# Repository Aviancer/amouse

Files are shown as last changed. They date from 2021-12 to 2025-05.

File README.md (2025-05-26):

# amouse

```
  __ _   _ __  ___ _  _ ___ ___ 
 / _` | | '  \/ _ \ || (_-</ -_)
 \__,_| |_|_|_\___/\_,_/__/\___====____
```

Anachro Mouse, a usb to serial mouse adapter.

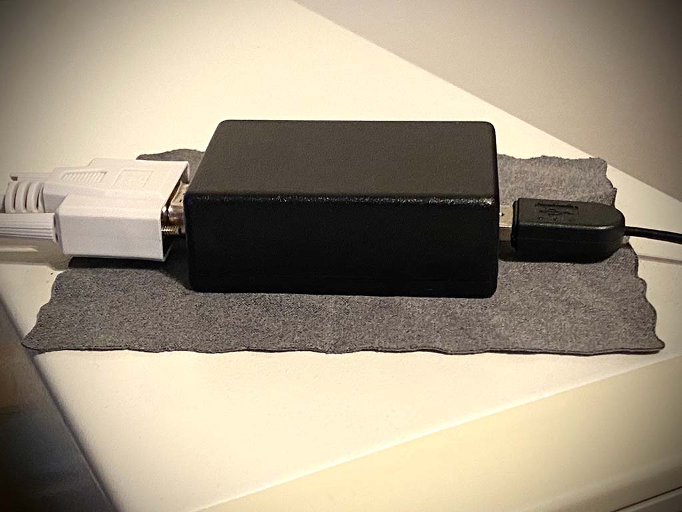
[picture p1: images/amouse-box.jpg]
Picture of a black box with USB and serial connector


This software will convert USB mouse inputs to a selectable serial mouse protocol for retro hardware. This way you can use a Raspberry Pico, a Raspberry Pi or an existing modern PC/laptop to mouse on your retro system.

If you do feel a bit more adventurous and would like to build a stand-alone adapter device, I have included the code to do this using a Raspberry Pico microcontroller. A circuit diagram is provided under the `diagrams` folder.

The adapter has been tested to work with DOS, Windows 3.1, Windows 95 and 98 serial mouse drivers so far.

# New and changed

Notable changes for users, see more detailed changelogs at the releases.

Since v1.6.0:
- Console is now accessed with `backspace` rather than `enter` key to avoid Windows ATDT autodetect
- Saving settings to non-volatile memory, both for Pico an Linux builds

Since v1.5.0:
- Fixed a regression in initializing mouse with Windows environments
- Changed from FIFO to queue based multi-threading model for much improved reliability in serial transmission

# Features

Input aggregation from USB data rates to serial, for making the mouse response smooth and accurate.

On-the-fly sensitivity control and easy menu based configuration over serial terminal.
Emulated protocols:
- Wheeled Microsoft IntelliPoint mouse (Both DOS and Windows Plug and Play compatible).
- Generic two button Microsoft serial Mouse, without wheel.
- Logitech three button mouse.

All protocols work on DOS and Windows with the appropriate mouse driver or ctmouse.exe available from the FreeDOS project.

Since version 1.6.0 you are able to save your settings to non-volatily flash memory or disk so that they get automatically loaded when the adapter starts.

# Controls

## On-the-fly sensitivity control

Once the mouse is initialized - hold down both left and right mouse buttons. Then additionally:
- Scroll mouse wheel up to add sensitivity
- Scroll mouse wheel down to reduce sensitivity

One mouse wheel click adds/reduces sensitivity by a factor of 0.2, you can adjust sensitivity between 0.2 and 3.0.

## Serial console for configuration

<video src="https://user-images.githubusercontent.com/80006672/147396198-eb4ab52f-2a5a-4799-a7e4-8fb58865289f.mp4" controls="controls" style="max-width: 720px;">
</video>

A serial console feature is provided for more advanced configuration of the features of the mouse adapter, allowing for more than what is practical with just mouse button shortcuts. The serial console uses the same COM port used for acting as a serial adapter and you can toggle between the modes easily. This way the computer can be used to configure the adapter and no additional hardware is required, on Linux you can of course also use direct cli arguments.

Things you can configure (as of 1.6.0):
- Sensitivity
- Serial mouse protocol
- Swap left and right buttons
- Store settings in non-volatile memory (flash)

Open a serial terminal program (kermit, etc) to the same COM port you connected the mouse to, use the following settings:
```
1200 baud
7 data bits
No parity
1 stop bit
No hardware flow control
```

Press `backspace` (in some terminals `ctrl+backspace`) to bring up the serial console, the adapter will switch to configuration mode and a menu will open. If you get scrambled characters, check all your terminal settings.
For an example you can enter: `3 11<enter>` to change the mouse sensitivity to 11 (1.1 in the above sensitivity scale).

Enter the `exit command` to the serial console after you are done configuring amouse, returning it to adapter mode. If you changed protocols, you may need to re-initialize the OS mouse driver.

### Saving your options

You can save your preferred settings so that they will be automatically loaded when you power on the adapter. These settings will be written to the same non-volatile flash memory that also stores the firmware. The currently selected settings are persisted to flash once you tell the adapter to save them, before that safe defaults will be loaded on boot. However once you have saved your settings, these settings will be automatically used the next time the adapter is powered on.

Navigate to `6) Read or write settings (Flash)` from the main menu. You can then:

1) Show help
2) Load settings from flash
3) Save settings to flash <--

If you make changes to your settings without saving, these will only remain in the memory until the adapter is power cycled. To update your settings you will need to save the settings to flash again. Using the on-the-fly sensitivity adjustment also changes the volatile in-memory settings.

With the Linux build the settings will be written to the users home directory at `~/.amouse.conf` (if you run the program as root with sudo, this means `/root/.amouse.conf`), in the same binary format as the Pico build uses.

# Linux version

Tested to work also on a Raspberry Pi.

The Linux version can be found under the 'linux' subdirectory. I wrote this initially as a prototype before moving on to writing a Raspberry Pico implementation of the same, but have continued to keep it up to date also.

The mouse is by default captured in exclusive mode so you can use it without worrying about sending inputs to the system running it. Non-exclusive mode is also supported.

## Requirements
- A working C building environment.
- libevdev (tested with 1.11.0-1, probably works with other versions)
- Superuser privileges (simple) or access to raw mouse and serial devices (requires changing perms, exercise left up to reader).
- A serial port on the computer running amouse. You can get away with a cheap USB to Serial adapter.
- A retro PC or alike for fun or productivity, I recommend using ctmouse.exe driver under DOS. amouse works fine for Windows 3.1, 95 and 98 drivers also.

## Preferred 
- The serial port (retropc)RTS -> CTC(amouse) pin is used by the mouse driver at the other end to signal initializing a mouse, amouse catches this for timing and responds appropriately. However this can also be manually timed if there are no other options.

## Build & install
```
cd linux
make
make install
```

make install will copy the binary to `/usr/local/bin` by default.

## Usage example

```
sudo amouse -m /dev/input/by-id/usb-<yourdevice>-event-mouse -s /dev/ttyUSB0 
```

Where ttyUSB0 in this case is for example a USB serial port adapter, naturally you can use an actual serial port as well if your computer features one.
Note that evdev requires access to a -event- generating device, just picking any `/dev/input` mouse device will not work.

You can try the following for finding the device file for your mouse:
`ls /dev/input/by-id/*event-mouse*`

If you are unable to find your mouse under there, you may have to look try out the various `/dev/input/event*` files instead.
The following may also provide some pointers for figuring out a `/dev/input/event*` number: `grep -H '' /sys/class/input/*/name`

If your serial cable/adapter isn't fully pinned (missing a CTS pin), you may use the `-i` (immediate ident) option bypass the automatic handling. In this case you will need to manually time it and launch the mouse driver and amouse at the same time. The timing can be pretty tight and require multiple attempts.

You can use the `-W` option to have the software write your current mouse options as the default settings when you run the software, the configuration will be written to `~/.amouse.conf` in the same binary format that is used to store the settings in flash for the stand-alone Pico adapter. As such it does not save any Linux specific settings like device paths.

`amouse -h` will also print help and list of flags available.

# Raspberry Pico (RP2040) version

Provides a stand-alone adapter running on a Raspberry Pico microcontroller for converting from USB to Serial Mouse.

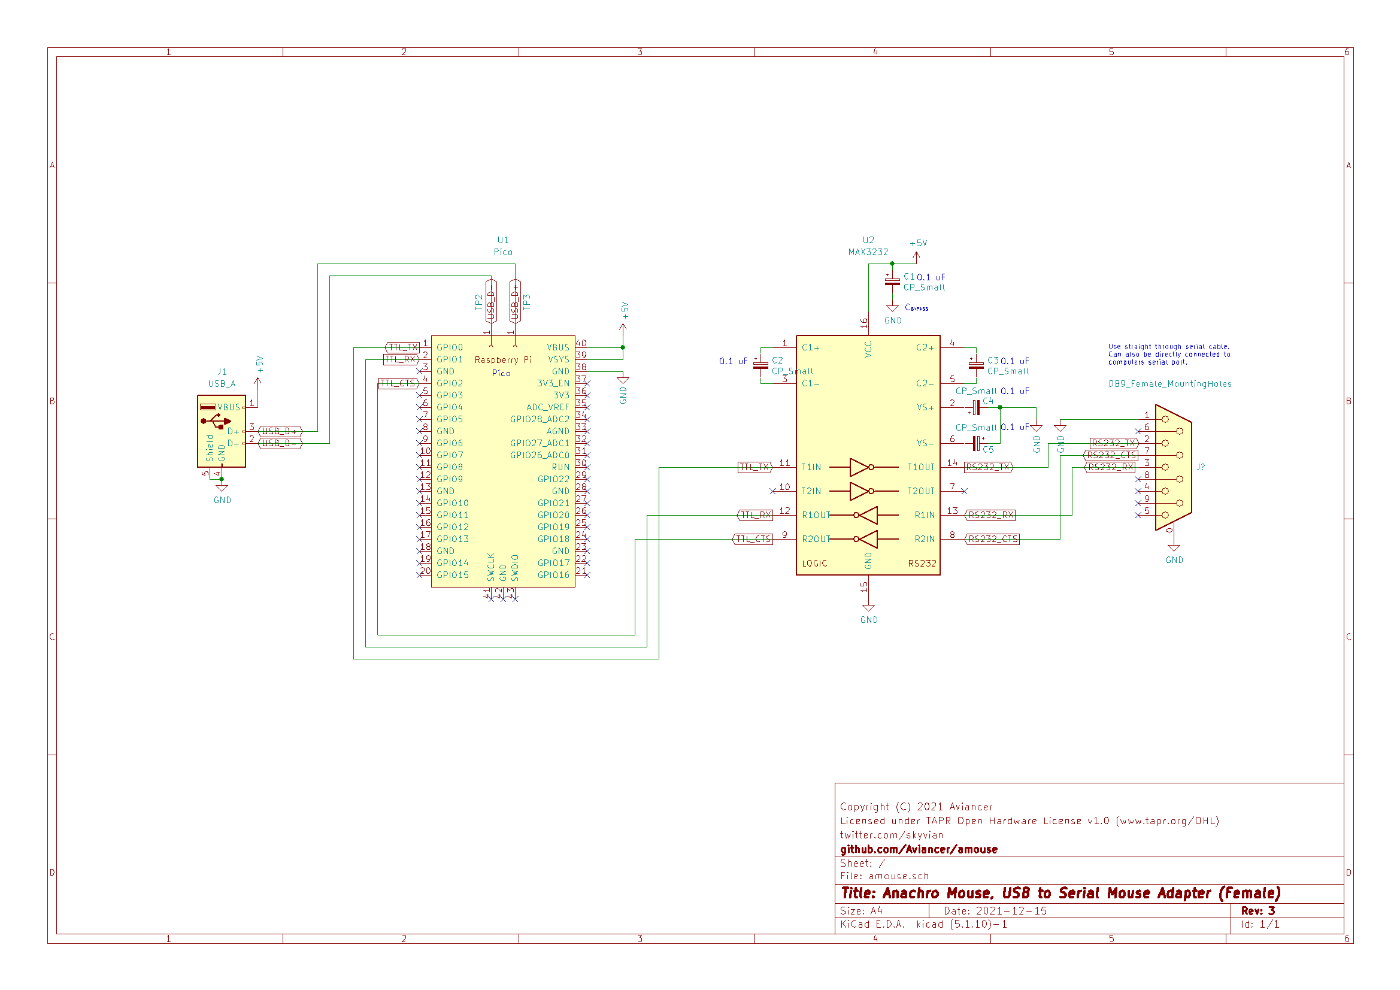
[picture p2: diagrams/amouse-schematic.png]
Electronic schematic of the adapter


## Requirements
- Basic soldering skills
- Working C building environment
- cmake version > 3.12
- Raspberry Pico SDK (Should auto-pull from git on cmake)

### Components
- A Raspberry Pico microcontroller
- One DIP MAX3232 chip or compatible, with 1x TX + 2x RX pins available.
- 5x 0.1uF capacitors (charge pumps for MAX3232, cbypass, etc)
- Serial header with RX, TX and CTS available
- USB-A header to solder on, or alternatively a USB micro to USB-A host adapter for connecting a USB mouse to the Pico USB port
- Few bits of wire/board to make connections
- A suitable serial cable for connecting from the adapter to the computers serial port (see diagram)
- A way to provide 5v power to the Pico (a USB charger or battery could be ideal)

## Build & install
```
cd pico/build
cmake ..
make
```

This will build `amouse.uf2` which can be flashed onto a Raspberry Pico.

To enter flashing mode with Raspberry Pico by holding down the small white button while connecting it to a USB port. Then simply copy `amouse.uf2` onto the Pico USB drive.

See `diagrams` directory for how to wire the Pico correctly to talk to a serial port.

## Usage example

- Connect your USB mouse to the adapter
- Connect the adapters serial port to the computers serial port
- Provide the Pico with 5v power (and appropriate grounding, etc)
- Run a mouse driver/start a serial mouse using OS on the computer

Provided that everything is connected up correctly, the adapter will auto-detect any mouse driver initialization from the PC and by default introduce itself as a Microsoft mouse. You can then use your USB mouse as a serial mouse.

# Planned future features

- [x] Storing settings like sensitivity and used mouse protocol in a non-volatile manner.
- [ ] Mouse Systems protocol.
- [ ] Graceful handling of reconnecting USB devices.
- [ ] DOS-native software for setting options without serial terminal program.

# FAQ

Q: Why Anachro Mouse?
A: A serial mouse is pretty anachronistic these days, but there's plenty of people who enjoy retro hardware and might find this rather useful. It also makes for a nice wordplay with 'a mouse' and 'anachromous'.

Q: Why a serial mouse?
A: Lots of people enjoy playing with retro PC hardware and I wanted there to be something that's easy with minimal hardware to use as a serial mouse while the latter are becoming increasingly rare or are breaking.

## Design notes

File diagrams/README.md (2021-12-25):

# Diagrams

All schematics were created in kicad.

## amouse-schematic.png

Main schematic with female serial port, can also be directly connected to a computers serial port. Use a straight serial cable for connecting.

## amouse-schematic_male.png 

Alternative schematic with male serial port, can also be directly connected to a computers serial port. Use a null modem cable with swapped RX/TX for connecting.

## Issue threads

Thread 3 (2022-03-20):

Does not work with Windows 3.11

mk2987, 2022-03-20:
First of all, thanks for creating this project!

I installed this on my Linux desktop and connected via serial port to my retro 486 machine. cutemouse.exe (tried v 2.1b and v 1.9) is able to detect the mouse. As a test, the mouse works fine in EDIT.COM. I run amouse with -d, and it keeps generating debug output about mouse telemetry as I move the pointer.
But Windows 3.11 isn't able to detect / use the mouse. I tried all the options available while setting up the mouse with c:\windows\setup.exe:
1) Choosing "Microsoft or IBM PS/2" makes the mouse pointer to not appear at all. The amouse binary on the Linux machine also stops generating any debug output. Maybe this is indicative of a problem?
2) Choosing Genius or Mouse Systems serial mouse makes the pointer appear, but it jumps about randomly. But I wouldn't expect this to work anyway.

I run the amouse binary this way (tried both with and without -w, no difference)
`sudo ./bin/amouse -w -d -m /dev/input/by-id/usb-MOSART_Semi._2.4G_Keyboard_Mouse-if01-event-mouse -s /dev/ttyS0`

Any ideas what could be going wrong?
Thanks!

Aviancer, 2022-03-20:
Thanks for contacting me, I'm happy to hear of interest in the project - it helps keep me motivated!

The current builds do have some problems being identified by Windows, since it seems like Windows is handling serial mouse identification in a bit special fashion that's been difficult to implement reliably. I've had a few builds that were being successfully recognized but had some latency issues in Windows, and I've been trying to rework my code so that both problems could be resolved for the next release.

I've actually not really done testing against Windows 3.1/3.11 but have concentrated primarily on DOS and 95/98. I'd be certainly interested in having proper support for Windows 3.X as well though, and testing that is helpful. My own kvm and physical hardware testing/capture setups don't cover 3.X currently.

I believe basic two button Microsoft mouse protocol might be working better at this time on the dev branch, but full on IntelliMouse PnP negotiation on 95 certainly is still failing. I'll check on this and get back to you. You can also find the dev branch here:
https://github.com/Aviancer/amouse/tree/dev

Aviancer, 2022-03-20:
I made a minor adjustment to the dev branch (commit 0d0d909) that allows the Linux build cli options (-w in this case) to select between MSWHEEL and MS2BUTTON protocols again - I'm also reworking this for more protocols. I tested that the 2 button basic Microsoft protocol is identing properly against Windows 95 and sent mouse movement and clicks.

The following command should hopefully now work for you with a standard Microsoft serial mouse driver on Windows (I am not able to test 3.X specifically right now):
`sudo ./bin/amouse -w -m /dev/input/by-id/usb-MOSART_Semi._2.4G_Keyboard_Mouse-if01-event-mouse -s /dev/ttyS0`

Let me know how it goes.

mk2987, 2022-03-21:
Thanks for the fix! I can confirm that as of commit `0d0d909` on the `dev` branch, the mouse works in Windows 3.11 when run as a two button MS mouse with the `-w` option of `amouse`. In Windows setup, I selected "Microsoft or IBM PS/2" as the mouse type. The command line used was:
`sudo ./bin/amouse -w -m /dev/input/by-id/usb-MOSART_Semi._2.4G_Keyboard_Mouse-if01-event-mouse -s /dev/ttyS0`

mk2987, 2022-03-21:
FWIW my mouse is connected to my Linux machine via a USB keyboard-mouse switch, it's great that the switch doesn't have any impact on amouse functionality. I did not notice any unacceptable latency either.

Aviancer, 2022-03-22:
Great, thanks for confirming that the change fixes the issue for Windows 3.X as well. This is a temporary fix and I need to rework selecting mouse protocols on the Linux build to allow more than two values to be selected (Logitech proto is now implemented also).

Happy to hear it's working nicely through the switch as well, I think it should work in most cases as long as there's nothing in between that would introduce the device as something else than as a mouse.

seritools, 2023-09-01:
Hey, I've built a Pi Pico amouse setup using an off-the-shelf MAX3232 to serial adapter (those that have RTS and CTS exposed) for use with my 486 machine, thank you for this project!

I'm also running into slight issues with Windows 3.11 - the mouse is fully detected and working under DOS (using the ctmouse driver), however under Windows, moving the mouse while any slightly CPU-intensive thing happens (starting Windows, starting a program, etc) it freezes the mouse. I can still see the status LED on the Pico lit up, and can see the TX led on the MAX3232 adapter blinking when moving the mouse.

A workaround seems to just reset the mouse while Windows is running, for some reason (e.g. start ctmouse in a dos window from within Windows again). Any idea what the issue could be?

Aviancer, 2025-04-28:
It's been a bit, but I've fixed a bunch of performance issues and some resulting regressions in mouse ident against Windows. The whole serial transmission logic has been reworked from FIFO based multi-threading to queue based multi-threading in the latest release. Hopefully this helps!!

Aviancer, 2025-05-14:
Alright! Tested both the stand-alone and the Linux build on Windows 3.1 with all the currently supported mouse protocols, everything looks good with building from commit 158756513d3dd1b3699b8a7b7d7ba0533516820f. Will probably be later released as 1.6.x, hoping to still implement the rest of configuration persistence.

Closed 2025-05-25.

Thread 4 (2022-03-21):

Makefile change needed to link on Raspbian 11

mk2987, 2022-03-21:
While amouse builds fine on my x86 Linux machine (Arch Linux), it was failing at link time on my Raspberry Pi:
`$ make
gcc -g -Wall -c src/include/serial.c -o src/include/serial.o
gcc -g -Wall -c src/../../shared/utils.c -o src/include/utils.o
gcc -g -Wall -c src/../../shared/mouse.c -o src/include/mouse.o
gcc -g -Wall -levdev -I/usr/include/libevdev-1.0/libevdev -I./include -o bin/amouse src/include/serial.c src/include/wrappers.c src/amouse.c ../shared/mouse.c ../shared/utils.c
/usr/bin/ld: /tmp/cclZh5iy.o: in function `open_usbinput':
/home/mkaushik/usb/amouse/linux/src/amouse.c:131: undefined reference to `libevdev_new_from_fd'
/usr/bin/ld: /home/mkaushik/usb/amouse/linux/src/amouse.c:136: undefined reference to `libevdev_has_event_type'
/usr/bin/ld: /home/mkaushik/usb/amouse/linux/src/amouse.c:137: undefined reference to `libevdev_has_event_code'
/usr/bin/ld: /home/mkaushik/usb/amouse/linux/src/amouse.c:138: undefined reference to `libevdev_has_event_code'
/usr/bin/ld: /home/mkaushik/usb/amouse/linux/src/amouse.c:139: undefined reference to `libevdev_has_event_code'
/usr/bin/ld: /home/mkaushik/usb/amouse/linux/src/amouse.c:140: undefined reference to `libevdev_has_event_code'
/usr/bin/ld: /home/mkaushik/usb/amouse/linux/src/amouse.c:141: undefined reference to `libevdev_has_event_code'
/usr/bin/ld: /home/mkaushik/usb/amouse/linux/src/amouse.c:142: undefined reference to `libevdev_free'
/usr/bin/ld: /tmp/cclZh5iy.o: in function `main':
/home/mkaushik/usb/amouse/linux/src/amouse.c:233: undefined reference to `libevdev_new_from_fd'
/usr/bin/ld: /home/mkaushik/usb/amouse/linux/src/amouse.c:324: undefined reference to `libevdev_next_event'
collect2: error: ld returned 1 exit status
make: *** [Makefile:30: amouse] Error 1
`
To fix this, we need to add the `--no-as-needed` flag to CFLAGS in the Makefile, or move `-levdev` to be after the object file names in the final build command. Apparently the linker on Raspbian 11 has `--as-needed` set by default (see the man page for ld for details on why this causes problems when -levdev is before the object files)

Aviancer, 2022-03-22:
I had a look over this and while I can't easily directly test this at the moment, I've changed the order of parameters for the final linking so that the libraries are included last after the objects. That appears to be the most compatible way to handle this issue as "--no-as-needed" is not a fully standard flag from what I'm seeing.

This change is in the current cba115f commit of the dev branch.

Aviancer, 2025-04-28:
No response in a few years so assuming fixed.

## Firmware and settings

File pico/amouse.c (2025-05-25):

/*
 *   __ _   _ __  ___ _  _ ___ ___ 
 *  / _` | | '  \/ _ \ || (_-</ -_)
 *  \__,_| |_|_|_\___/\_,_/__/\___=====_____)
 *
 * Anachro Mouse, a usb to serial mouse adaptor. Copyright (C) 2021-2025 Aviancer <oss+amouse@skyvian.me>
 *
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
 * You should have received a copy of the GNU Lesser General Public License along with this library; 
 * if not, write to the Free Software Foundation, Inc., 59 Temple Place, Suite 330, Boston, MA 02111-1307 USA
 *
*/

#include <time.h>
#include "stdbool.h"
#include "pico/flash.h"
#include "pico/stdlib.h"
#include "pico/multicore.h"
#include "pico/util/queue.h"
#include "hardware/irq.h"

#include "include/version.h"
#include "include/serial.h"
#include "include/storage.h"
#include "include/usb.h"
#include "../shared/console.h"
#include "../shared/utils.h"
#include "../shared/mouse.h"
#include "../shared/mouse_defs.h"
#include "../shared/settings.h"

#include "bsp/board.h"
#include "tusb.h"

// Technically could support multiple mice connected to the same system if we kept more mouse states in memory.


/*** Mouse state variables ****/

mouse_state_t mouse; // int values default to 0 

static uint32_t time_tx_target;  // Serial transmit timers target time
static uint32_t time_rx_target;  // Serial receive timers target time

uint8_t serial_buffer[2] = {0}; // Buffer for inputs from serial port.

// Aggregate movements before sending
CFG_TUSB_MEM_SECTION static hid_mouse_report_t usb_mouse_report_prev;

const uint LED_PIN = PICO_DEFAULT_LED_PIN;
bool led_state = false;

/*** Timing ***/

void queue_tx(mouse_state_t *mouse) {
  // Update timer target for next transmit
  // Use different send rate depending on protocol used (3 or 4 bytes)
  if(mouse->update > 3) { time_tx_target = time_us_32() + U_SERIALDELAY_4B; }
  else                  { time_tx_target = time_us_32() + U_SERIALDELAY_3B; }
}


/*** Mouse specific USB handling ***/

int test_mouse_button(uint8_t buttons_state, uint8_t button) {
  if(buttons_state & button) { return 1; }
  return 0;
}

static inline void process_mouse_report(mouse_state_t *mouse, hid_mouse_report_t const *p_report) {
 
  uint8_t button_changed_mask = p_report->buttons ^usb_mouse_report_prev.buttons; // xor to set bits true if any state is different.
  //if(button_changed_mask & p_report->buttons) { // Could be used to act only on any button down press.
  if(button_changed_mask) { // If button pressed or released
    mouse->force_update = 1;

    mouse->lmb = test_mouse_button(p_report->buttons, MOUSE_BUTTON_LEFT);
    mouse->rmb = test_mouse_button(p_report->buttons, MOUSE_BUTTON_RIGHT);
    push_update(mouse, mouse->mmb);

    if((button_changed_mask & MOUSE_BUTTON_MIDDLE)) {
      mouse->mmb = test_mouse_button(p_report->buttons, MOUSE_BUTTON_MIDDLE);
      if(g_mouse_protocol[g_mouse_options.protocol].buttons > 2) {
        push_update(mouse, true); 
      }
    }
  }
    
  // ### Handle relative movement ###
  // Clamp to larger than valid protocol output values to allow for sensitivity scaling.
  if(p_report->x) {
    mouse->x += p_report->x;
    mouse->x  = clampi(mouse->x, -36862, 36862); 
    push_update(mouse, mouse->mmb);
  }
  if(p_report->y) {
    mouse->y += p_report->y;
    mouse->y  = clampi(mouse->y, -36862, 36862);
    push_update(mouse, mouse->mmb);
  }
  if(p_report->wheel) {
    mouse->wheel += p_report->wheel;
    mouse->wheel  = clampi(mouse->wheel, -63, 63);
    if(g_mouse_protocol[g_mouse_options.protocol].wheel) {
      push_update(mouse, true); 
    }
  }

  // Update previous mouse state
  usb_mouse_report_prev = *p_report;
}

// External interface for delivering mouse reports to process_mouse_report()
// Allows keeping static context within amouse.c while tinyusb handling can be shifted to usb.c
extern void collect_mouse_report(hid_mouse_report_t const* p_report) {
  process_mouse_report(&mouse, p_report); // Passes full context with mouse and report without having to make them external/non-static.
}


/*** Core 1 thread to offload serial writes ***/

void core1_tightloop() {
  flash_safe_execute_core_init(); // Ensure core1 can be safetied for duration of writing to flash

  uint8_t serial_data;
  while(1) {
    //serial_queue_pop(&g_serial_queue, &serial_data); // TODO: Test if returns correct data now
    queue_remove_blocking(&g_serial_queue, &serial_data);
    uart_putc_raw(uart0, serial_data); // TODO: Make UART configurable.
  }
}

/*** Main init & loop ***/

int main() {

  // Initialize serial parameters 
  mouse_serial_init(0); // uart0

  // Initialize the global serial data queue
  queue_init(&g_serial_queue, sizeof(uint8_t), 80);

  // Should be launched before any interrupts
  multicore_launch_core1(core1_tightloop);

  // Set up initial state 
  //enable_pins(UART_RTS_BIT | UART_DTR_BIT);
  reset_mouse_state(&mouse);
  mouse.pc_state = CTS_UNINIT;

  // Set safe default options, support mouse wheel.
  g_mouse_options.protocol = PROTO_MSWHEEL;
  g_mouse_options.wheel = 1;
  g_mouse_options.sensitivity = 1.0;

  // Attempt to load saved settings from storage
  settings_decode(ptr_flash_settings(), &g_mouse_options);

  // Initialize USB
  tusb_init();

  // Onboard LED
  gpio_init(LED_PIN);
  gpio_set_dir(LED_PIN, GPIO_OUT);

  // Set initial serial timer targets
  time_tx_target = time_us_32() + U_SERIALDELAY_3B;
  time_rx_target = time_us_32() + U_FULL_SECOND; 

  bool cts_pin = false;

  while(1) {

    // Check for request for serial console
    // Repeating non-blocking reads is slow so instead we queue checks every now and then with timer.
    if(time_reached(time_rx_target)) {
      if(serial_read(0, serial_buffer, 1) > 0) {
        // Use backspace to enable console instead of \n\r to avoid ATDT autodetection on Windows
        if(serial_buffer[0] == '\b') {
    	    console(0);
        }
      }
      time_rx_target = time_us_32() + U_FULL_SECOND;
    }

    // Mouse handling

    cts_pin = gpio_get(UART_CTS_PIN);

    if(cts_pin) { // Computers RTS low, only pin we care about for MS drivers, etc.
      if(mouse.pc_state == CTS_UNINIT) { mouse.pc_state = CTS_LOW_INIT; }
      else if(mouse.pc_state == CTS_TOGGLED) { mouse.pc_state = CTS_LOW_RUN; }
    }

    // Mouse initiaizing request detected
    if(!cts_pin && (mouse.pc_state != CTS_UNINIT && mouse.pc_state != CTS_TOGGLED)) {
      gpio_put(LED_PIN, false); // DEBUG
      mouse.pc_state = CTS_TOGGLED;
      mouse_ident(0, g_mouse_options.wheel);
    }

    // Transmit only once we are initialized at least once. Unlike in DOS, Windows drivers will set CTS pin 
    // low after init which would inhibit transmitting. We will trust the driver to re-init if needed.
    if(mouse.pc_state > CTS_LOW_INIT) {
      if(!led_state) {
      	led_state = true;
      }

      tuh_task(); // tinyusb host task

      if(time_reached(time_tx_target) || mouse.force_update) {
        runtime_settings(&mouse);
      	input_sensitivity(&mouse);
	      update_mouse_state(&mouse);

      	queue_tx(&mouse); // Update next serial timing
	      if(mouse.update > 0) { serial_write(0, mouse.state, mouse.update); }
        reset_mouse_state(&mouse);
      }
    }

  }

  return(0);
}

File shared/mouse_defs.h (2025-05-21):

/*
 * Anachro Mouse, a usb to serial mouse adaptor. Copyright (C) 2025 Aviancer <oss+amouse@skyvian.me>
 *
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
 * You should have received a copy of the GNU Lesser General Public License along with this library; 
 * if not, write to the Free Software Foundation, Inc., 59 Temple Place, Suite 330, Boston, MA 02111-1307 USA
 *
*/

#ifndef MOUSE_DEFS_H_
#define MOUSE_DEFS_H_

/* Protocol definitions */
#define MOUSE_LMB_BIT 5 // Defines << shift for bit position
#define MOUSE_RMB_BIT 4
#define MOUSE_MMB_BIT 4 // Shift 4 times in 4th byte

typedef struct mouse_proto {
  char    name[12];
  uint8_t serial_ident[2]; // M, M3, MZ..
  int     serial_ident_len;
  int     buttons;
  bool    wheel;
  int     report_len;
} mouse_proto_t;

enum MOUSE_PROTOCOLS {
  PROTO_MS2BUTTON = 0, // 2 buttons, 3 bytes
  PROTO_LOGITECH  = 1, // 3 buttons, 3-4 bytes
  PROTO_MSWHEEL   = 2, // 3 buttons, wheel, 4 bytes.
  PROTO_MOUSESYS  = 3  // Mouse systems, TBD
};

// Delay between data packets for 1200 baud
#define U_FULL_SECOND 1000000L      // 1s in microseconds
#define U_SERIALDELAY_1B  7500      // 1 byte
#define U_SERIALDELAY_3B  22700     // 3 bytes (microseconds)
#define U_SERIALDELAY_4B  30000     // 4 bytes (microseconds)
// 1200 baud (bits/s) is 133.333333333... bytes/s
// 44.44.. updates per second with 3 bytes.
// 33.25.. updates per second with 4 bytes.
// ~0.0075 seconds per byte, target time calculated for 4 bytes.
#define NS_FULL_SECOND    1000000000L // 1s in nanoseconds
#define NS_SERIALDELAY_1B   7500000   // 1 byte
#define NS_SERIALDELAY_3B   22700000  // 3 bytes
#define NS_SERIALDELAY_4B   30000000  // 4 bytes

// Struct for storing information about accumulated mouse state
typedef struct mouse_state {
  int pc_state; // Current state of mouse driver initialization on PC.
  uint8_t state[4]; // Mouse state
  int x, y, wheel;
  int update; // How many bytes to send
  bool lmb, rmb, mmb, force_update;
} mouse_state_t;

// Struct for user settable mouse options
typedef struct mouse_opts {
  uint protocol;
  float sensitivity; // Sensitivity coefficient
  bool wheel;
  bool swap_buttons;
} mouse_opts_t;

// States of mouse init request from PC
enum PC_INIT_STATES {
  CTS_UNINIT   = 0, // Initial state
  CTS_LOW_INIT = 1, // CTS pin has been set low, wait for high.
  CTS_TOGGLED  = 2, // CTS was low, now high -> do ident.
  CTS_LOW_RUN  = 3  // CTS drops low post-initialization, Windows behavior.
};

#endif // MOUSE_DEFS_H_

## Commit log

2021-06-28 Linux: Mousewheel fix. Immediate mode now properly bypasses CTS check. Mouse state now stored in struct like with RP2040.
    [amouse.c, serial.c, serial.h]
2021-07-21 Pico: Initial commit of Raspberry Pico compatible codebase. Doc updates.
2021-07-27 Added schematic for stand-alone adapter.
    [amouse.kicad_pcb, amouse.sch]
2021-07-27 Added cbypass capacitor to Pico schematic, minor changes.
    [amouse.sch]
2021-07-28 Pico: Add runtime configurability for sensitivity.
2021-11-23 Pico: Implemented on-the-fly sensitivity control.
2021-11-28 Shared/Pico: WIP: Re-factor shared functions into their own include.
2021-11-28 Shared/Pico/Linux: WIP: Continue refactoring for shared code.
2021-11-28 Shared/Pico/Linux: WIP: Bringing Linux build in line with Pico.
2021-11-29 Pico: Fixed sensitivity controls.
    [amouse.c]
2021-11-30 Linux: Reverse PC pin logic for mouse init.
    [amouse.c]
2021-12-01 Linux/Pico: WIP: Abstracted opening uart interface to follow same pattern on Linux/Pico. Initial two-way serial communication.
2021-12-02 Pico: WIP: Rebuild entire tinyusb and HID handling due to changes in library.
2021-12-02 Pico: Comment out USB uart logging calls.
2021-12-02 Pico: Fixes building with current tusb library. Extract new tusb interface to usb.c/usb.h. Clean up.
    [amouse.c]
2021-12-02 Pico/Linux: Update version numbers.
2021-12-17 Shared/Linux/Pico: WIP: Fix off by one serial read functions. Serial terminal + backspace works with workaround.
    [serial.c]
2021-12-17 Shared/Linux/Pico: Functional serial console for both builds.
2021-12-19 Shared/Linux/Pico: Replaced sscanf with custom implementation to avoid library bloat (3x size). Pico serial console now callable.
    [amouse.c]
2021-12-19 Shared/Linux/Pico: Mouse options now settable from serial console.
2021-12-21 Shared/Linux/Pico: Configurable mouse protocol, swappable left/right mouse buttons. Current settings can be displayed.
    [amouse.c, serial.c]
2021-12-21 Linux/Pico: On-the-fly sensitivity control remains available even if protocol doesn't have mouse wheel.
    [amouse.c]
2021-12-25 Shared/Linux/Pico: Fixed old off-by-one bug with serial writes. Wrappers for architecture dependent functions called from independent code.
    [amouse.c, serial.c]
2021-12-25 Diagrams/Shared/Linux: Switched to female serial port, can be connected direct to computer. Updated documentation. Fixed console sleep timer for Linux.
    [amouse_maleserial.sch]
2021-12-26 Project: Add schematic to README.md.
2022-01-04 Shared/Linux: WIP: MS IntelliMouse PnP and Windows compatibility progress, removed variable packet length optimization (protocol incompatible).
    [amouse.c, serial.c]
2022-01-05 Shared/Linux/Pico: Initial working implementation of Windows compatible MS IntelliMouse. CTS handling re-written to be Windows compatible. Solved PnP report for drivers etc, appropriately encoded.
    [amouse.c, serial.c]
2022-01-05 Pico: Improve mouse responsiveness significantly by offloading serial writes to Core 1.
2022-01-07 Shared/Linux/Pico: Extended multi-protocol support. Added Logitech mouse protocol.
2022-01-14 Shared/Linux/Pico: Console now enables with two consequtive enter presses. Ignore ATDT/Windows device autodetection.
2022-01-14 Linux: Fix parsing cli options. Print help on '-?' as well.
    [amouse.c]
2022-01-15 Shared/Linux/Pico: WIP: Update version numbers, documentation. Fix Pico USB side regression.
    [amouse.c]
2022-01-15 Linux/Pico: Use 'backspace' rather than 'enter' for calling console, avoids hardware autodetect/ATDT and retains unbuffered responsiveness on Pico.
    [amouse.c, serial.c, serial.h]
2022-02-27 Pico: WIP: Mouse ident works with interrupt, MSWHEEL PNP ident sent correctly.
    [amouse.c, serial.c]
2022-03-04 Pico: WIP: Fixing ident/mouse protocol under Windows.
    [amouse.c]
2022-03-22 Linux/Pico: WIP: Makefile, include libs after objects for Raspbian build compatibility (sets --as-needed).
2022-03-31 Linux/Shared: Compiles on Raspbian bullseye, fixes issue #4. Some GCC versions don't like defining variables inside switch blocks it turns out.
    [amouse.c]
2022-03-31 Linux/Shared: Allow Linux cli to set responsiveness/sensitivity. aprint() no longer terminates line itself.
    [amouse.c]
2022-05-01 Linux/Pico: WIP: Abort PNP ident if CTS goes low. Windows ident maybe works, but no mouse inputs.
2022-05-01 Pico: A little clean up.
2025-04-28 Pico: Fix build against updated tinyusb, removed tuh_cdc_xfer_isr callback. Define collect_mouse_report() in usb.h
2025-04-28 Pico, Shared: WIP, sources prettified. Builds with using global queue.
2025-04-28 Pico: Working mswheel and ident with queues, tested against Win95 on hw.
2025-04-29 Pico: Use backspace to enable console due to Windows ATDT autodetect. Reduce direct access to serial queue internals, instead provide serial_queue_pop().
2025-04-29 Pico: Fix serial_queue_pop() to behave more C-like.
    [amouse.c, serial.c, serial.h]
2025-04-30 Pico, Shared: WIP, initial work on configuration persisting and storage.
2025-05-02 Pico, Shared, Linux: WIP, created binary representation of settings. CRC-8.
2025-05-12 Pico, Linux, Shared: Settings funcs use pointers, introduce settings encode/decode tests, move mouse definitions to own header.
2025-05-12 Pico, Shared: Add include guards. Storage header.
2025-05-14 WIP: Logic works, serial transmission broken (same char)
    [serial.c]
2025-05-14 Pico, Shared: Reverted to old serial queue read (WIP), working multi-level serial menu (flash).
    [amouse.c, serial.c]
2025-05-21 Pico, Shared: WIP, settings saving and loading. Linux: Added temporary storage stubs.
2025-05-21 Linux, Pico, Shared: Clean up consts from flash memory refs, on Pico it would make sense but less on Linux.
2025-05-21 Pico, Linux, Shared: WIP: Break out serial console from shared/mouse.c to shared/console.c
2025-05-22 Pico: Steps to fix serial_queue_pop()
    [amouse.c, serial.c, serial.h]
2025-05-22 Pico, Linux, Shared: Rename global extern variables to start with g_ for better context.
2025-05-22 Linux: amouse.c indentation fix.
    [amouse.c]
2025-05-22 Pico: 'mouse' does not need to be a global in amouse.c
2025-05-25 Linux, Pico, Shared: WIP: Functional flash storage. Console broken.
    [serial.c, serial.h]
2025-05-25 Pico, Shared: Use static allocation for console binary settings. Working backspace in console.

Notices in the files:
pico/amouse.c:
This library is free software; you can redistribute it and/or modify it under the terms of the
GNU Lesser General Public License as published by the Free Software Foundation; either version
